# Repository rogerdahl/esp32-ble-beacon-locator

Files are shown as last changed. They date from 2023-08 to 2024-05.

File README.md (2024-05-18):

# BLE iBeacon locator

This is the firmware for a DIY gadget to locate nearby iBeacons.

<p float="left">
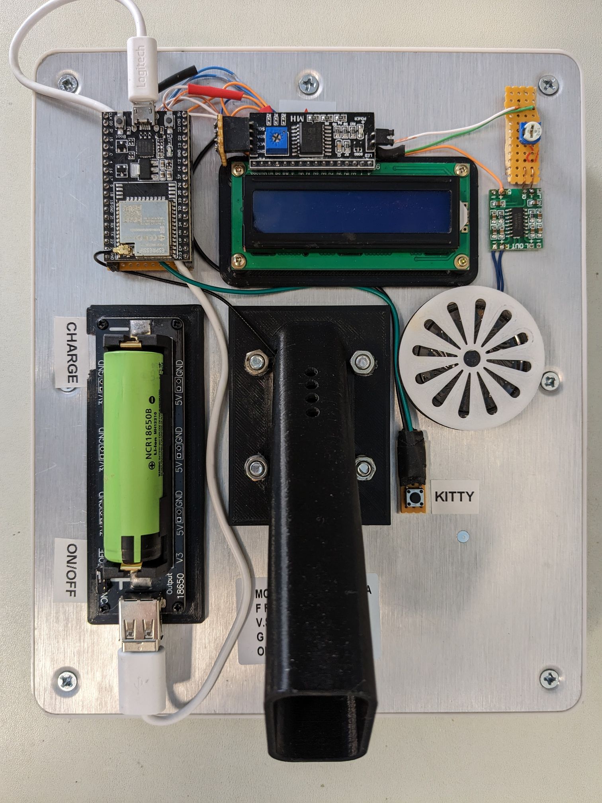
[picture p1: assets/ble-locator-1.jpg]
Locator 1

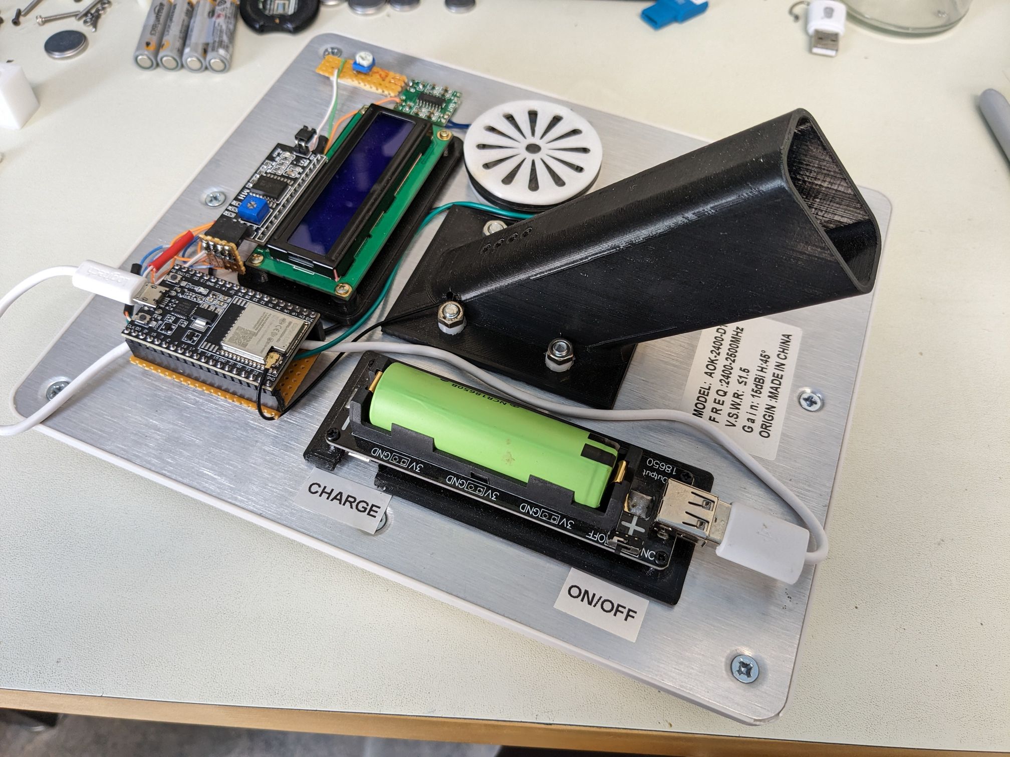
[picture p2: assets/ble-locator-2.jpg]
Locator 2

</p>

## Usage

After turning the locator on, select the beacon to locate with the "kitty" button. When the locator picks up a ping from the selected beacon, a brief "beep" will sound. The pitch of the sound indicates signal strength, with higher pitch for stronger signal. Slowly point the device from side to side and walk in the direction indicated by generally higher pitched beeps in order to arrive at the location of the beacon.

The LCD shows the name of the selected beacon along with the signal strength and time since previous ping.

Adjust the speaker volume with the small pot.

The range appears to be a couple of hundred feet if there is line of sight to the beacon.

Finding my cat, Bela, who is sleeping outside with a BLE tag on his collar:

<p float="left">
<a href="https://youtu.be/n8z9IQo4tqQ">
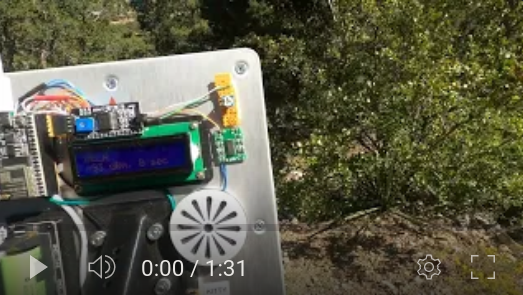
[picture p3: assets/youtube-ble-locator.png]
Locator 3

</a>

## Building

I'll flesh this section out if there's interest.

This can be built with inexpensive parts from AliExpress or similar. The handle, LCD and battery mounting plates and speaker cover are 3D printed.

The components and the handle are mounted on the back of a directional 2.4 GHz panel antenna. The LCD and battery are fasted to the mounting plates with screws, and the plates are fastened to the antenna with double-sided foam tape. The circuit board is fastened directly with double-sided foam tape. 

Use an app such as [BLE Scanner](https://play.google.com/store/apps/details?id=com.macdom.ble.blescanner&hl=en_US&gl=US&pli=1) to find the device addresses of iBeacons to be used with the locator. Add the device addresses and display names at the top of `main.c`. 

Connections:

| LCD | ESP32 |
|---|---|
| GND | GND |
| VCC | VIN |
| SDA | GPIO 21 |
| SCL | GPIO 22 |

| Speaker | ESP32  |
|---|---|
| GND | GND |
| VCC | VIN |
| Channel | GPIO 4 |

Search terms for parts:

| Part | Search |
|---|---|
| ESP32 | ESP32-WROOM-32U development board with connection for external antenna |
| LCD | LCD1602 16x2 PCF8574 |
| Battery | 18650 charging shield |
| Speaker amp | PAM8403 module |
| Speaker | 0.5W small speaker |
| Antenna | 2.4GHz WiFi directional panel antenna |

### Troubleshooting

- If there's a build error, try `idf.py reconfigure`.

## 3D printed parts

`./print/handle.FCStd`
<p>
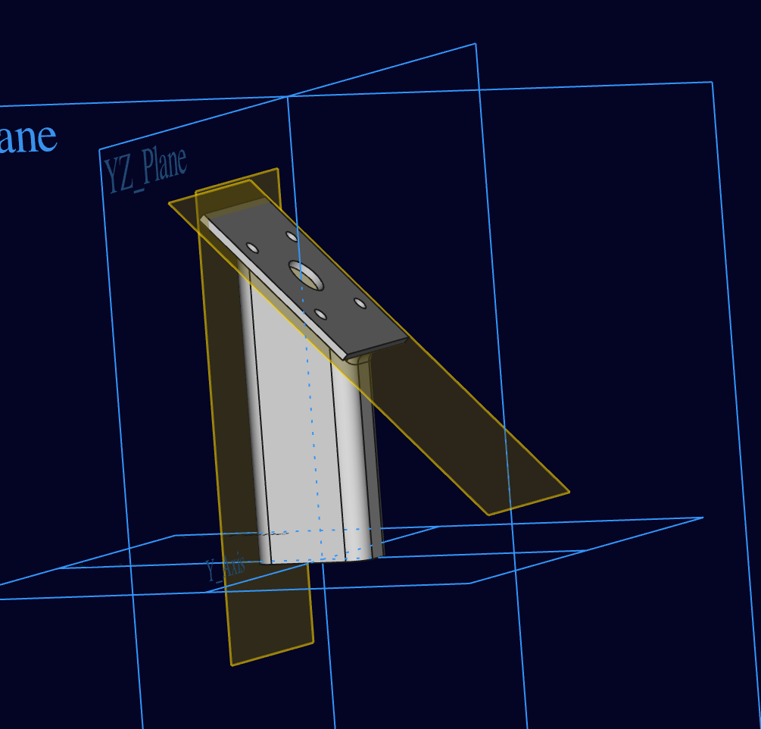
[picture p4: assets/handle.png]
Antenna Handle

</p>

## Notes

- The detected signal strength has quite a bit of random variation, but is consistent enough to indicate the general direction to walk to get closer to the beacon.
- This device works with iBeacon tags that do not turn themselves off when not connected to a phone. It also works with any other BLE device that is broadcasting advertising packets.
- If the BLE device does not show up in apps such as BLE Scanner, it will probably not work with this device.

## Technologies

- [esp32](https://www.espressif.com/en/products/socs/esp32)
- [esp-idf](https://github.com/espressif/esp-idf)
- [esp-idf-lib](https://github.com/UncleRus/esp-idf-lib) (for driving the LCD)

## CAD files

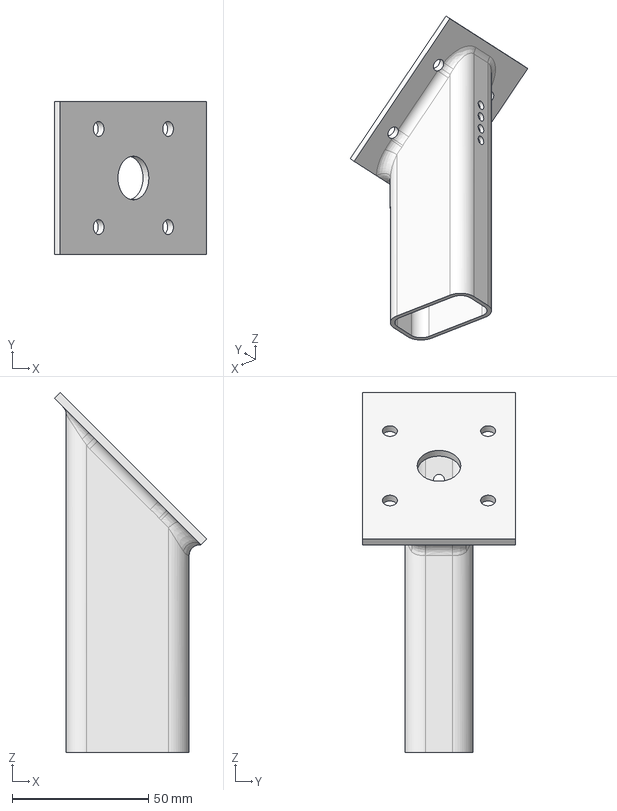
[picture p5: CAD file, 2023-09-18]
print/antenna_handle.FCStd
55.9 x 56.0 x 132.0 mm

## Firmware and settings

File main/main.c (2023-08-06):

#include "freertos/FreeRTOS.h"

#include "host/ble_hs.h"
#include "host/util/util.h"

#include "nimble/nimble_port.h"
#include "nimble/nimble_port_freertos.h"

#include "nvs_flash.h"
#include "services/gap/ble_svc_gap.h"
#include <pcf8574.h>

#include "beep.h"
#include "blecent.h"
#include "lcd.h"


static const char *TAG = "main";


struct BEACON {
    // char[32] complete_local_name;
    char *nickName;
    ble_addr_t bleAddr;
};

struct BEACON BEACONS[] = {
    // Complete Local Name = Kensington Eureka 4936
    {
        "RACHAEL",
        // The Address bytes are required in reverse order.
        // Regular order, from phone: 0x78, 0xc5, 0xe5, 0xa1, 0x49, 0x36
        {0x00, {0x36, 0x49, 0xa1, 0xe5, 0xc5, 0x78}},
    },
    // Complete Local Name = Kensington Eureka 5727
    {
        "BELA",
        // Regular order, from phone: 0x78, 0xc5, 0xe5, 0xa1, 0x57, 0x27
        {0x00, {0x27, 0x57, 0xa1, 0xe5, 0xc5, 0x78}},
    },
    {0}
    // Something
    // {0x00, {0x66, 0x28, 0x15, 0xc4, 0x98, 0x3f}},
    // {0x00, {0x02, 0x6c, 0x40, 0xfd, 0x2a, 0x86}};
};


// GPIO5:  Select BLE address to listen for
#define GPIO_BUTTON_SELECT_BEACON 5
#define GPIO_INPUT_PIN_SEL (1ULL << GPIO_BUTTON_SELECT_BEACON)
#define ESP_INTR_FLAG_DEFAULT 0

volatile int listenBeaconIndex = 0;
volatile int lastDbm = 0;
volatile int secondsSinceLast = 0;

static void selectBeaconDebounceTask(void *arg);
void ble_store_config_init(void);
static int blecent_gap_event(struct ble_gap_event *event, void *arg);
static void blecent_on_reset(int reason);
static void blecent_on_sync(void);
void blecent_host_task(void *param);
void gpio_isr_select_beacon_handler(void *arg);
static void secondCounterTask(void *arg);


void app_main(void)
{
    esp_log_level_set("*", ESP_LOG_ERROR);

    ESP_LOGD(TAG, "### MAIN START");

    int rc;

    /* Initialize NVS — it is used to store PHY calibration data */
    esp_err_t ret = nvs_flash_init();
    if (ret == ESP_ERR_NVS_NO_FREE_PAGES || ret == ESP_ERR_NVS_NEW_VERSION_FOUND) {
        ESP_ERROR_CHECK(nvs_flash_erase());
        ret = nvs_flash_init();
    }
    ESP_ERROR_CHECK(ret);

    ESP_ERROR_CHECK(i2cdev_init());

    lcd_init();

    lcd_print(0, "Starting...");

    ESP_LOGD(TAG, "ledc_init() START");
    ledc_init();
    ESP_LOGD(TAG, "ledc_init() END");

    // Not available and not needed?
    // ESP_ERROR_CHECK(esp_nimble_hci_and_controller_init());

    ESP_LOGD(TAG, "nimble_port_init() START");
    nimble_port_init();
    ESP_LOGD(TAG, "nimble_port_init() END");

    /* Configure the host. */
    ble_hs_cfg.reset_cb = blecent_on_reset;
    ble_hs_cfg.sync_cb = blecent_on_sync;
    ble_hs_cfg.store_status_cb = ble_store_util_status_rr;

    /* Initialize data structures to track connected peers. */
    rc = peer_init(MYNEWT_VAL(BLE_MAX_CONNECTIONS), 64, 64, 64);
    assert(rc == 0);

    /* Set the default device name. */
    rc = ble_svc_gap_device_name_set("ble-finder");
    assert(rc == 0);

    ble_store_config_init();

    nimble_port_freertos_init(blecent_host_task);

    // Button interrupts

    gpio_config_t io_conf = {};
    io_conf.intr_type = GPIO_INTR_NEGEDGE;
    io_conf.pin_bit_mask = GPIO_INPUT_PIN_SEL;
    io_conf.mode = GPIO_MODE_INPUT;
    io_conf.pull_up_en = 1;
    gpio_config(&io_conf);

    // install gpio isr service
    gpio_install_isr_service(ESP_INTR_FLAG_DEFAULT);
    // Hook ISR handler for specific GPIO pin
    gpio_isr_handler_add(GPIO_BUTTON_SELECT_BEACON, gpio_isr_select_beacon_handler, (void *) GPIO_BUTTON_SELECT_BEACON);

    // printf("Minimum free heap size: %d bytes\n", esp_get_minimum_free_heap_size());

    xTaskCreate(secondCounterTask, "secondCounterTask", configMINIMAL_STACK_SIZE * 5, NULL, 5, NULL);

    lcd_print(0, BEACONS[listenBeaconIndex].nickName);

    ESP_LOGD(TAG, "### MAIN END");

    // We don't have to enter an endless loop here.
}

static void selectBeaconDebounceTask(void *arg)
{
    lcd_print(0, BEACONS[listenBeaconIndex].nickName);
    vTaskDelay(pdMS_TO_TICKS(500));
    gpio_intr_enable(GPIO_BUTTON_SELECT_BEACON);
    vTaskDelete(NULL);
}

/**
 * Initiates the GAP general discovery procedure.
 */
static void blecent_scan(void)
{
    uint8_t own_addr_type;
    struct ble_gap_disc_params disc_params;
    int rc;

    /* Figure out address to use while advertising (no privacy for now) */
    rc = ble_hs_id_infer_auto(0, &own_addr_type);
    if (rc != 0) {
        ESP_LOGE(TAG, "error determining address type; rc=%d\n", rc);
        return;
    }

    // We're scanning continuously and want to see repeated advertisements
    disc_params.filter_duplicates = 0;

    /**
     * Perform a passive scan.  I.e., don't send follow-up scan requests to
     * each advertiser.
     */
    disc_params.passive = 1;

    /* Use defaults for the rest of the parameters. */
    disc_params.itvl = 0;
    disc_params.window = 0;
    disc_params.filter_policy = 0;
    disc_params.limited = 0;

    rc = ble_gap_disc(own_addr_type, BLE_HS_FOREVER, &disc_params,
                      blecent_gap_event, NULL);
    if (rc != 0) {
        ESP_LOGE(TAG, "Error initiating GAP discovery procedure; rc=%d\n",
                 rc);
    }
}

// Convert RSSI dBm (signal strength) to audible frequency in Hz.
// Stronger signal gives higher pitch.
// dBm is 127 is unavailable.
int dbm_to_hz(int dbm)
{
    int hz = -(-dbm - 100) * 20;
    if (hz < 10) {
        hz = 10;
    }
    if (hz > 900) {
        hz = 900;
    }
    return hz;
}

// Format address msg and address.
// msg must be 0-4 chars.
// E.g: ADDR3649a1e5c578
void addr_to_str(char *buf, int maxlen, char *msg, ble_addr_t *addr)
{
    // hh was added in C99 and performs a cast to byte. This is to make up for type information that is lost when
    // passing variadic parameters to printf().
    snprintf(buf, maxlen, "%s %02hhx:%02hhx:%02hhx:%02hhx:%02hhx:%02hhx",
             msg,
             addr->val[0],
             addr->val[1],
             addr->val[2],
             addr->val[3],
             addr->val[4],
             addr->val[5]);
}

void log_addr(char *msg, ble_addr_t *addr)
{
    char buf[128];
    addr_to_str(buf, 128, msg, addr);
    ESP_LOGD(TAG, "%s", buf);
}

void beep_rssi(int8_t rssi)
{
    int freq_hz = dbm_to_hz(rssi);
    beep(freq_hz, 250);
}

int addr_are_equal(ble_addr_t *a, ble_addr_t *b)
{
    return ble_addr_cmp(a, b) == 0;
}

/**
 * The nimble host executes this callback when a GAP event occurs.  The
 * application associates a GAP event callback with each connection that is
 * established.  blecent uses the same callback for all connections.
 *
 * @param event                 The event being signalled.
 * @param arg                   Application-specified argument; unused by
 *                                  blecent.
 *
 * @return                      0 if the application successfully handled the
 *                                  event; nonzero on failure.  The semantics
 *                                  of the return code is specific to the
 *                                  particular GAP event being signalled.
 */
static int blecent_gap_event(struct ble_gap_event *event, void *arg)
{
    if (event->type != BLE_GAP_EVENT_DISC) {
        return 0;
    }

    ESP_LOGD(TAG, "listenBeaconIndex: %d", listenBeaconIndex);

    int8_t rssi = event->disc.rssi;
    ble_addr_t *addr = &event->disc.addr;

    // 127 is a reserved value for unavailable signal strength, meaning it's probably not a beacon.
    if (rssi == 127) {
        return 0;
    }

    // int ret;
    // struct ble_hs_adv_fields fields;
    //
    // ret = ble_hs_adv_parse_fields(&fields, event->disc.data, event->disc.length_data);
    // ESP_ERROR_CHECK(ret);
    //
    // if (fields.name_is_complete) {
    //   ESP_LOGE(TAG, "NAME: %s", fields.name);
    //   ESP_LOGE(TAG, "LEN: %d", fields.name_len);
    // }
    //
    // print_adv_fields(&fields);

    log_addr("RCV ", addr);
    // lcd_print_addr("RCV ", addr);

    if (addr_are_equal(addr, &BEACONS[listenBeaconIndex].bleAddr)) {
        beep_rssi(rssi);
        lastDbm = rssi;
        secondsSinceLast = 0;
    }
    // else {
    //   lcd_print_addr("UNK ", addr);
    // }

    return 0;
}

void blecent_on_reset(int reason)
{
    ESP_LOGE(TAG, "Resetting state; reason=%d\n", reason);
}

void blecent_on_sync(void)
{
    int rc;

    /* Make sure we have proper identity address set (public preferred) */
    rc = ble_hs_util_ensure_addr(0);
    assert(rc == 0);

    /* Begin scanning for a peripheral to connect to. */
    blecent_scan();
}

void blecent_host_task(void *param)
{
    ESP_LOGD(TAG, "BLE Host Task Started");
    /* This function will return only when nimble_port_stop() is executed */
    nimble_port_run();
    nimble_port_freertos_deinit();
}

void gpio_isr_select_beacon_handler(void *arg)
{
    gpio_intr_disable(GPIO_BUTTON_SELECT_BEACON);

    listenBeaconIndex += 1;
    if (BEACONS[listenBeaconIndex].nickName == NULL) {
        listenBeaconIndex = 0;
    }

    lastDbm = 0;
    secondsSinceLast = 0;

    xTaskCreate(selectBeaconDebounceTask, "selectBeaconDebounceTask", configMINIMAL_STACK_SIZE * 5, NULL, 5, NULL);
}

void secondCounterTask(void *arg)
{
    TickType_t xLastWakeTime = xTaskGetTickCount();
    for (;;) {
        lcd_print(1, "%ld dBm, %ld sec", lastDbm, secondsSinceLast);
        ++secondsSinceLast;
        xTaskDelayUntil(&xLastWakeTime, pdMS_TO_TICKS(1000));
    }
}

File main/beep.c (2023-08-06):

#include <driver/ledc.h>

#include <esp_err.h>
#include <esp_log.h>

#include <freertos/FreeRTOS.h>
#include <freertos/task.h>

#include <math.h>


#define TAG "beep"

#define LEDC_TIMER              LEDC_TIMER_0
#define LEDC_MODE               LEDC_LOW_SPEED_MODE
#define LEDC_OUTPUT_IO          (4)
#define LEDC_CHANNEL            LEDC_CHANNEL_0
#define LEDC_DUTY_RES           LEDC_TIMER_10_BIT
// #define LEDC_DUTY_RES           (11)
// Set duty to 50%. ((2 ** 13) - 1) * 50% = 4095
// #define LEDC_DUTY               (4095)
#define LEDC_DUTY               (((1<<LEDC_DUTY_RES) - 1) / 2)
// Frequency in Hertz (10 Hz is lowest supported)
#define LEDC_FREQUENCY          (10) \

//
#define SINE_FACTOR 127.0 // measured for step size = 1 and no advantage (8.3MHz)
int STACK_SIZE = 8192;

void beep_start();
void beep_stop();

// The ESP32 has a nice sine wave generator, but it can only output on a couple of pins, which are
// not available on my dev board, so we settle for square waves, which can be output on pretty much any
// pin. We generate square waves with the LED Control (LEDC) PWM peripheral.
void ledc_init(void) {
  ledc_timer_config_t ledc_timer = {
      .speed_mode       = LEDC_MODE,
      .timer_num        = LEDC_TIMER,
      .duty_resolution  = LEDC_DUTY_RES,
      .freq_hz          = LEDC_FREQUENCY,
      .clk_cfg          = LEDC_AUTO_CLK
  };
  ESP_ERROR_CHECK(ledc_timer_config(&ledc_timer));

  ledc_channel_config_t ledc_channel = {
      .speed_mode     = LEDC_MODE,
      .channel        = LEDC_CHANNEL,
      .timer_sel      = LEDC_TIMER,
      .intr_type      = LEDC_INTR_DISABLE,
      .gpio_num       = LEDC_OUTPUT_IO,
      .duty           = LEDC_DUTY,
      .hpoint         = 0
  };
  ESP_ERROR_CHECK(ledc_channel_config(&ledc_channel));
  beep_stop();
}

struct beep_task_param_t {
  uint32_t freq_hz;
  int duration_ms;
} beep_task_param;


void beep_task(void *pvParameters) {
  ESP_LOGI(TAG, "beep freq_hz=%ld duration_ms=%d", beep_task_param.freq_hz, beep_task_param.duration_ms);
  ledc_set_freq(LEDC_MODE, LEDC_TIMER, beep_task_param.freq_hz);
  beep_start();
  vTaskDelay(pdMS_TO_TICKS(beep_task_param.duration_ms));
  beep_stop();
  vTaskDelete(NULL);
}

void beep_start() {
  ledc_set_duty(LEDC_MODE, LEDC_CHANNEL, LEDC_DUTY);
  ledc_update_duty(LEDC_MODE, LEDC_CHANNEL);
}

void beep_stop() {
  ledc_set_duty(LEDC_MODE, LEDC_CHANNEL, 0);
  ledc_update_duty(LEDC_MODE, LEDC_CHANNEL);
}


void beep(uint32_t freq_hz, int duration_ms) {
  TaskHandle_t h = NULL;
  beep_task_param.freq_hz = freq_hz;
  beep_task_param.duration_ms = duration_ms;
  xTaskCreate(beep_task, "beep_task", STACK_SIZE, NULL, 0, &h);
  configASSERT(h);
}
